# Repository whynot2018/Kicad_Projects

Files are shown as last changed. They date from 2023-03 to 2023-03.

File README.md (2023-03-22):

# Kicad_Projects

### 1.25-15V 0-350mA bench power supply 
https://danyk.cz/minizdroj2_en.html
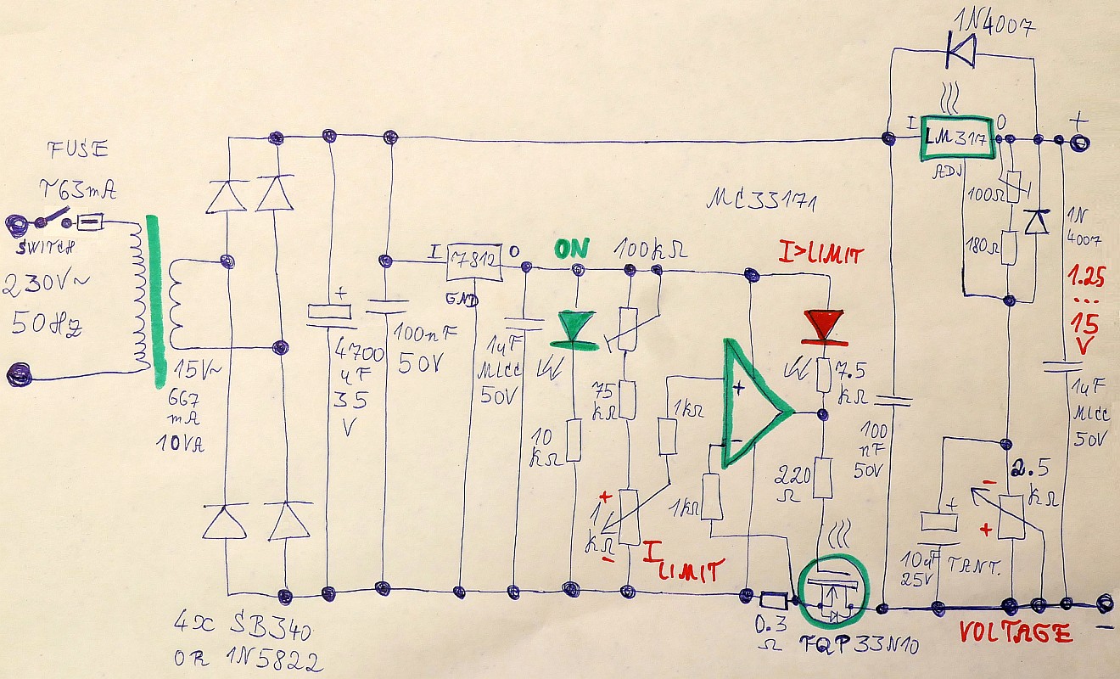
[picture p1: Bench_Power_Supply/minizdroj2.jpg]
1.25-15V 0-350mA bench power supply


```
This is a simple linear bench DC voltage power supply with adjustable current limit. The output voltage can be set in the range of 1.25 to 15V and the current limitation 0 to 350mA. The voltage regulation uses well-known LM317 circuit. The current limiter uses a 0.3 ohm current sensing resistor (shunt). You can also use 0.27 or 0.33 ohm one. A 7812 circuit regulates the voltage for the OpAmp and also works as a voltage reference. The MC33171 OpAmp compares the shunt voltage to the voltage on the slider of the potentiometer. If the shunt voltage is higher, the OpAmp output will reduce the gate voltage of the MOSFET (FQP33N10) and thus limit the current. Current limiting mode is indicated by a red LED. In the power supply I used MYRRA 44268 transformer with 15V output voltage, 10VA power and 667mA maximum current. The output voltage at no load is approx. 18.3V. The bridge rectifier is made of SB340 or 1N5822 Schottky diodes to minimize the voltage drop. The 100k trimmer allows you to fine-tune the maximum adjustable current limit value, the 100 ohm trimmer the maximum adjustable output voltage. The LM317 circuit can be replaced with a compatible LM338 or LM350. It is also possible to use LM1084, LM1085 or LM1086, which have a lower dropout, but also a lower maximum input voltage (only 30V).
Warning! The device is powered from the mains. If constructed improperly, mains voltage can get to the output and cause an electric shock! It can also cause a fire. Capacitors can remain charged even after disconnected from mains. I do not guarantee the information provided. You do everything at your own risk. I take no responsibility for any damage. 
```

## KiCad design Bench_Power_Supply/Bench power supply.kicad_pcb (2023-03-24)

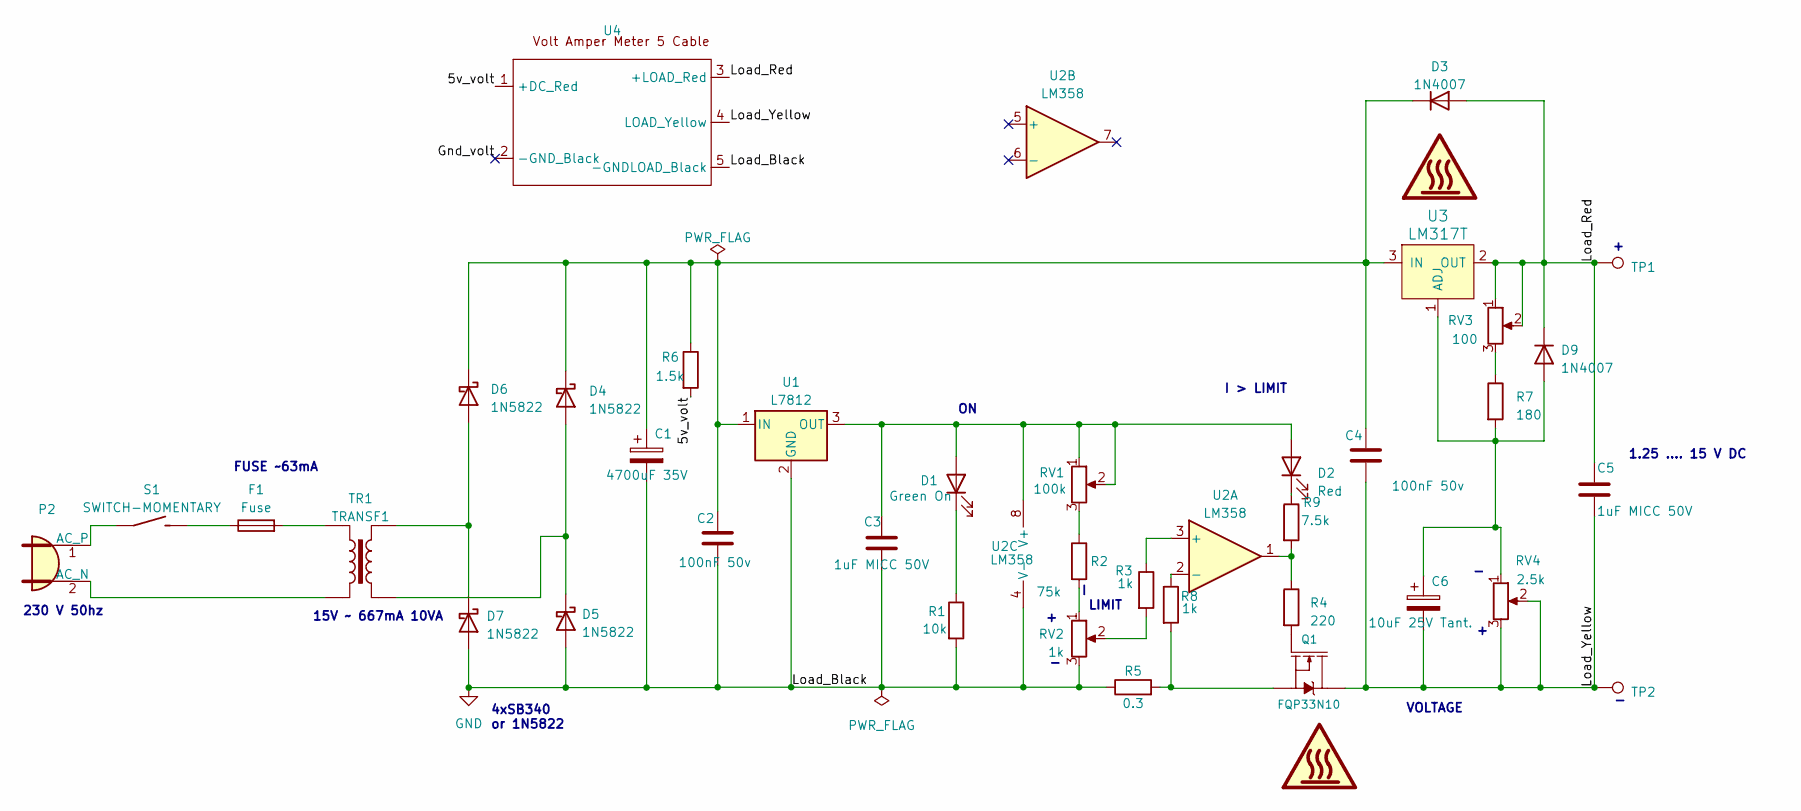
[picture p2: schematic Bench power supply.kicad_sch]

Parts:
C1: 4700uF 35V; CP_Radial_D8.0mm_P5.00mm
C2, C4: 100nF 50v; C_Disc_D7.5mm_W5.0mm_P7.50mm
C3, C5: 1uF MICC 50V; C_Disc_D7.5mm_W5.0mm_P7.50mm
C6: 10uF 25V Tant.; C_Disc_D8.0mm_W5.0mm_P5.00mm
D1: Green On; LED_D5.0mm
D2: Red; LED_D5.0mm
D3, D9: 1N4007; D_DO-41_SOD81_P10.16mm_Horizontal
D4, D5, D6, D7: 1N5822; D_DO-201AD_P15.24mm_Horizontal
F1: Fuse; Fuse_Littelfuse-LVR200
P2: Conn_WallPlug; TerminalBlock_bornier-2_P5.08mm
Q1: FQP33N10; TO220V
R1: 10k; R_Axial_DIN0414_L11.9mm_D4.5mm_P15.24mm_Horizontal
R2: 75k; R_Axial_DIN0414_L11.9mm_D4.5mm_P15.24mm_Horizontal
R3, R8: 1k; R_Axial_DIN0414_L11.9mm_D4.5mm_P15.24mm_Horizontal
R4: 220; R_Axial_DIN0414_L11.9mm_D4.5mm_P15.24mm_Horizontal
R5: 0.3; R_Axial_DIN0414_L11.9mm_D4.5mm_P15.24mm_Horizontal
R6: 1.5k; R_Axial_DIN0414_L11.9mm_D4.5mm_P15.24mm_Horizontal
R7: 180; R_Axial_DIN0414_L11.9mm_D4.5mm_P15.24mm_Horizontal
R9: 7.5k; R_Axial_DIN0414_L11.9mm_D4.5mm_P15.24mm_Horizontal
RV1: 100k; Potentiometer_ACP_CA9-H3,8_Horizontal
RV2: 1k; Potentiometer_ACP_CA9-H3,8_Horizontal
RV3: 100; Potentiometer_ACP_CA9-H3,8_Horizontal
RV4: 2.5k; Potentiometer_ACP_CA9-H3,8_Horizontal
S1: SWITCH-MOMENTARY; SW_CuK_OS102011MA1QN1_SPDT_Angled
TP1: +; TestPoint_THTPad_2.5x2.5mm_Drill1.2mm
TP2: -; TestPoint_THTPad_2.5x2.5mm_Drill1.2mm
TR1: TRANSF1; TRANSFORMER
U1: L7812; TO-220F-3_Vertical
U2: LM358; DIP-8_W7.62mm_LongPads
U3: LM317T; TO-220-3; MPN LM317T; Digi-Key_PN 497-1575-5-ND
U4: Volt_Amper_Meter_5_Cable

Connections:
/5v_volt: R6.2, U4.1 (+DC_Red)
/Gnd_volt: U4.2 (-GND_Black)
/Load_Red: C5.1, D3.2 (A), D9.1 (K), RV3.1, RV3.2, TP1.1, U3.2 (OUT), U4.3 (+LOAD_Red)
/Load_Yellow: C4.2, C5.2, C6.2, Q1.2 (D), RV4.2, RV4.3, TP2.1, U4.4 (LOAD_Yellow)
GND: C1.2, C2.2, C3.2, D5.2 (A), D7.2 (A), R1.2, R5.1, RV2.3, U1.2 (GND), U2.4 (V-), U4.5 (-GNDLOAD_Black)
unnamed: C1.1, C2.1, C4.1, D3.1 (K), D4.1 (K), D6.1 (K), R6.1, U1.1 (IN), U3.3 (IN)
unnamed: C3.1, D1.2 (A), D2.2 (A), RV1.1, RV1.2, U1.3 (OUT), U2.8 (V+)
unnamed: D1.1 (K), R1.1
unnamed: D2.1 (K), R9.1
unnamed: D4.2 (A), D5.1 (K), TR1.3
unnamed: D6.2 (A), D7.1 (K), TR1.4
unnamed: C6.1, D9.2 (A), R7.2, RV4.1, U3.1 (ADJ)
unnamed: F1.2, TR1.1
unnamed: P2.2 (AC_N), TR1.2
unnamed: P2.1 (AC_P), S1.1
unnamed: Q1.1 (G), R4.2
unnamed: Q1.3 (S), R5.2, R8.2
unnamed: R2.1, RV1.3
unnamed: R2.2, RV2.1
unnamed: R3.2, RV2.2
unnamed: R4.1, R9.2, U2.1
unnamed: R7.1, RV3.3
unnamed: F1.1, S1.3 (2)
unnamed: R3.1, U2.3 (+)
unnamed: R8.1, U2.2 (-)

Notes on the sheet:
15V ~ 667mA 10VA
FUSE ~63mA
VOLTAGE
4xSB340 or 1N5822
I > LIMIT
I LIMIT
230 V 50hz
1.25 .... 15 V DC

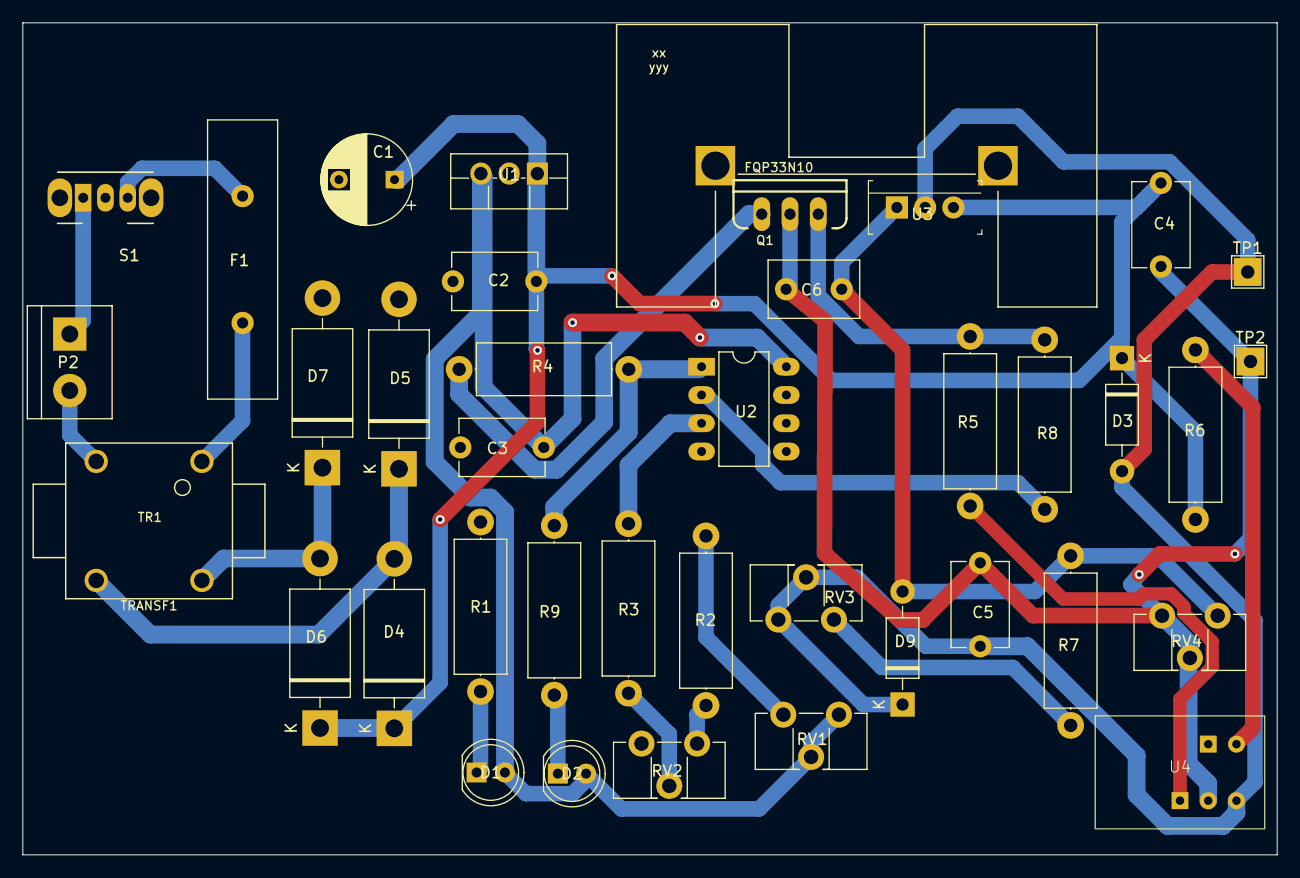
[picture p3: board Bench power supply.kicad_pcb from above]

Board: 2 copper layers, 112.8 x 74.8 mm, 39 parts (0 on the bottom side), 24 nets.

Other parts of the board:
xx: yyy; HEATSINK_PRT-9576
